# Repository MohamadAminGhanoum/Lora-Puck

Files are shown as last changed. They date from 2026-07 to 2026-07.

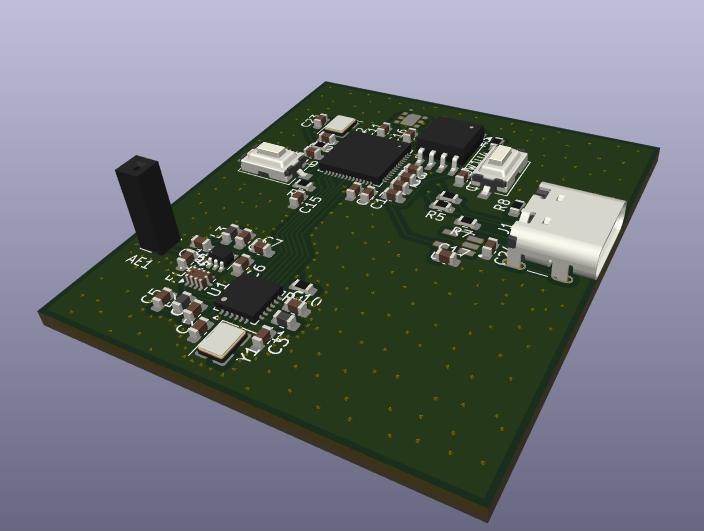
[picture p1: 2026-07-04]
assets/Screenshot 2026-07-03 at 01.11.49.png

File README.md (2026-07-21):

# Lora-Puck
im planning on doing the lorapuck, while adding some simple and accurate sensors, which certainly will make this Lora Puck a lot more useful to me. Im planning to make 2 pcbs, one i keep at home that can track the temperature of e.g my room, and one i can take with me anywhere, and this will allow me to recieve signals from my home LORA, and i will be recieving it to my other LORA puc that i carry with me.
NOTE: as i am making it in the EU, i should follow the european law of max. 868 MHz, and not 915 MHz like USA

## Schematics:



## PCB:



## 3d pic of pcb:




## BOM

|Name |Vendor |Quantity|Price in USD|Link |
|---|---|---|---|---|
|PCB |JLCPCB |5 |10 |JLCPCB |
|100nF capacitor  |LCSC |12 |self-sourced| |
|47nH inductor |LCSC |1 |0.23 |https://www.lcsc.com/product-detail/C440659.html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  |
|HTU21D |LCSC |2 |3.29 |https://www.lcsc.com/product-detail/C83479.html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 |
|RP2040 |LCSC |2 |1.99 |https://www.lcsc.com/product-detail/C2040.html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 |
|SX1262IMLTRT |LCSC |2 |6.51 |https://www.lcsc.com/product-detail/C191341.html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  |
| | | | | |
|AP2112K-3.3TRG1  |LCSC |5 |0.55 |https://www.lcsc.com/product-detail/C23380830.html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|
|W25Q128JVS |LCSC |2 |5.6 |https://www.lcsc.com/product-detail/C97521.html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 |
|10uF capacitor |LCSC |50 |1.75 |https://www.lcsc.com/product-detail/C1691.html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 |
|12nHz crystal |LCSC |20 |0.43 |https://www.lcsc.com/product-detail/C1332832.html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 |
|470nF cap |LCSC |100 |1.15 |https://www.lcsc.com/product-detail/C105526.html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  |
|1k resistor |LCSC |100 |0.76 |https://www.lcsc.com/product-detail/C2907002.html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|
|0900FM15K0039001E|LCSC |1 |0.61 |https://www.lcsc.com/product-detail/C7434807.html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 |
|100 ohm resistor |LCSC |1 |selfsourced | |
|32MHz |LCSC |2 |selfsourced | |
|3.3pF capacitor  |LCSC |100 |1.04 |https://www.lcsc.com/product-detail/C1660.html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 |
| 1uF capacitor |LCSC |50 |1.09 |https://www.lcsc.com/product-detail/C29936.html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  |
|5.1k resistor |LCSC |100 |0.24 |https://www.lcsc.com/product-detail/C2907044.html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|
|USB-c |LCSC |20 |1.41 |https://www.lcsc.com/product-detail/C2765186.html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|
|switch |LCSC |2 |selfsourced | |
|BLM15AX102SN1D |LCSC |100 |1.26 |https://www.lcsc.com/product-detail/C85815.html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  |
|27.4 ohm resistor|LCSC |2 |selfsourced | |
|1nF capacitor |LCSC |1 |1.46 |https://www.lcsc.com/product-detail/C100040.html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 |
| 39pF cap |LCSC |100 |0.52 |https://www.lcsc.com/product-detail/C107049.html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 |
| 15pF cap |LCSC |100 |0.57 |https://www.lcsc.com/product-detail/C107037.html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 |
| 47pF cap |LCSC |100 |0.61 |https://www.lcsc.com/product-detail/C105622.html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 |
| 9.1nH inductor  |LCSC |50 |0.54 |https://www.lcsc.com/product-detail/C395094.html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 |
| 10k resistor |LCSC |100 |0.51 |https://www.lcsc.com/product-detail/C98220.html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  |
|PE4259 |LCSC |2 |1.41 |https://www.lcsc.com/product-detail/C470892.html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 |
|15uH inductor |LCSC |20 |0.73 |https://www.lcsc.com/product-detail/C486329.html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 |
| | | | | |
| |Total cost w. shipping:|50 usd  | | |

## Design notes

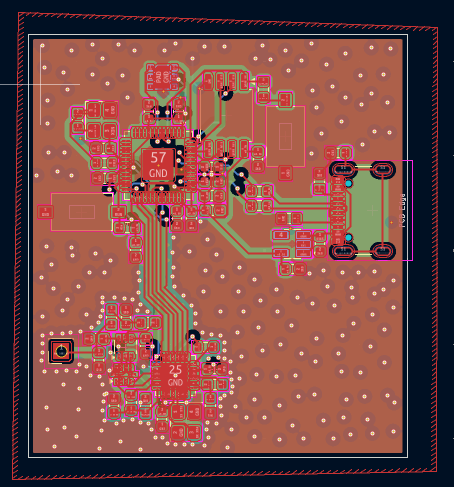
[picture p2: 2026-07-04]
assets/Screenshot 2026-07-03 at 01.11.20.png

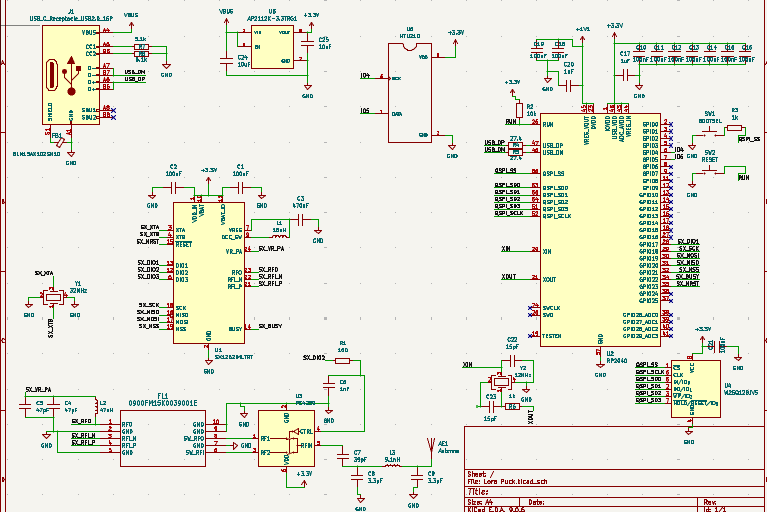
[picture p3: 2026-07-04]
assets/Screenshot 2026-07-04 at 22.49.37.png

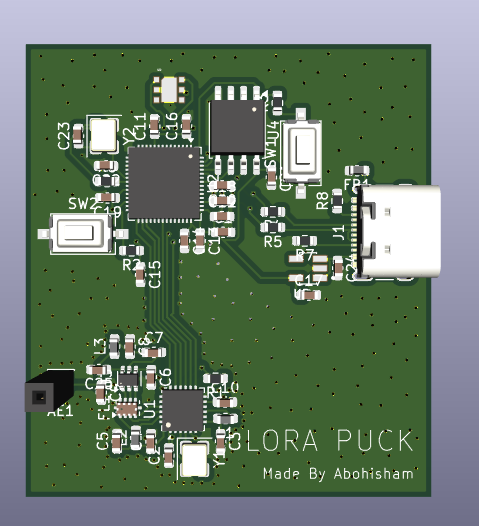
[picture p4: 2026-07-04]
assets/Screenshot 2026-07-03 at 01.14.08.png

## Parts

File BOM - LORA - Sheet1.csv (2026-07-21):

Name | Vendor | Quantity | Price in USD | Link
PCB | JLCPCB | 5 | 10 | JLCPCB
100nF capacitor | LCSC | 12 | self-sourced
47nH inductor | LCSC | 1 | 0.23 | https://www.lcsc.com/product-detail/C440659.html
HTU21D | LCSC | 2 | 3.29 | https://www.lcsc.com/product-detail/C83479.html
RP2040 | LCSC | 2 | 1.99 | https://www.lcsc.com/product-detail/C2040.html
SX1262IMLTRT | LCSC | 2 | 6.51 | https://www.lcsc.com/product-detail/C191341.html
AP2112K-3.3TRG1 | LCSC | 5 | 0.55 | https://www.lcsc.com/product-detail/C23380830.html
W25Q128JVS | LCSC | 2 | 5.6 | https://www.lcsc.com/product-detail/C97521.html
10uF capacitor | LCSC | 50 | 1.75 | https://www.lcsc.com/product-detail/C1691.html
12nHz crystal | LCSC | 20 | 0.43 | https://www.lcsc.com/product-detail/C1332832.html
470nF cap | LCSC | 100 | 1.15 | https://www.lcsc.com/product-detail/C105526.html
1k resistor | LCSC | 100 | 0.76 | https://www.lcsc.com/product-detail/C2907002.html
0900FM15K0039001E | LCSC | 1 | 0.61 | https://www.lcsc.com/product-detail/C7434807.html
100 ohm resistor | LCSC | 1 | selfsourced
32MHz | LCSC | 2 | selfsourced
3.3pF capacitor | LCSC | 100 | 1.04 | https://www.lcsc.com/product-detail/C1660.html
1uF capacitor | LCSC | 50 | 1.09 | https://www.lcsc.com/product-detail/C29936.html
5.1k resistor | LCSC | 100 | 0.24 | https://www.lcsc.com/product-detail/C2907044.html
USB-c | LCSC | 20 | 1.41 | https://www.lcsc.com/product-detail/C2765186.html
switch | LCSC | 2 | selfsourced
BLM15AX102SN1D | LCSC | 100 | 1.26 | https://www.lcsc.com/product-detail/C85815.html
27.4 ohm resistor | LCSC | 2 | selfsourced
1nF capacitor | LCSC | 1 | 1.46 | https://www.lcsc.com/product-detail/C100040.html
39pF cap | LCSC | 100 | 0.52 | https://www.lcsc.com/product-detail/C107049.html
15pF cap | LCSC | 100 | 0.57 | https://www.lcsc.com/product-detail/C107037.html
47pF cap | LCSC | 100 | 0.61 | https://www.lcsc.com/product-detail/C105622.html
9.1nH inductor | LCSC | 50 | 0.54 | https://www.lcsc.com/product-detail/C395094.html
10k resistor | LCSC | 100 | 0.51 | https://www.lcsc.com/product-detail/C98220.html
PE4259 | LCSC | 2 | 1.41 | https://www.lcsc.com/product-detail/C470892.html
15uH inductor | LCSC | 20 | 0.73 | https://www.lcsc.com/product-detail/C486329.html
 | Total cost w. shipping: | 50 usd

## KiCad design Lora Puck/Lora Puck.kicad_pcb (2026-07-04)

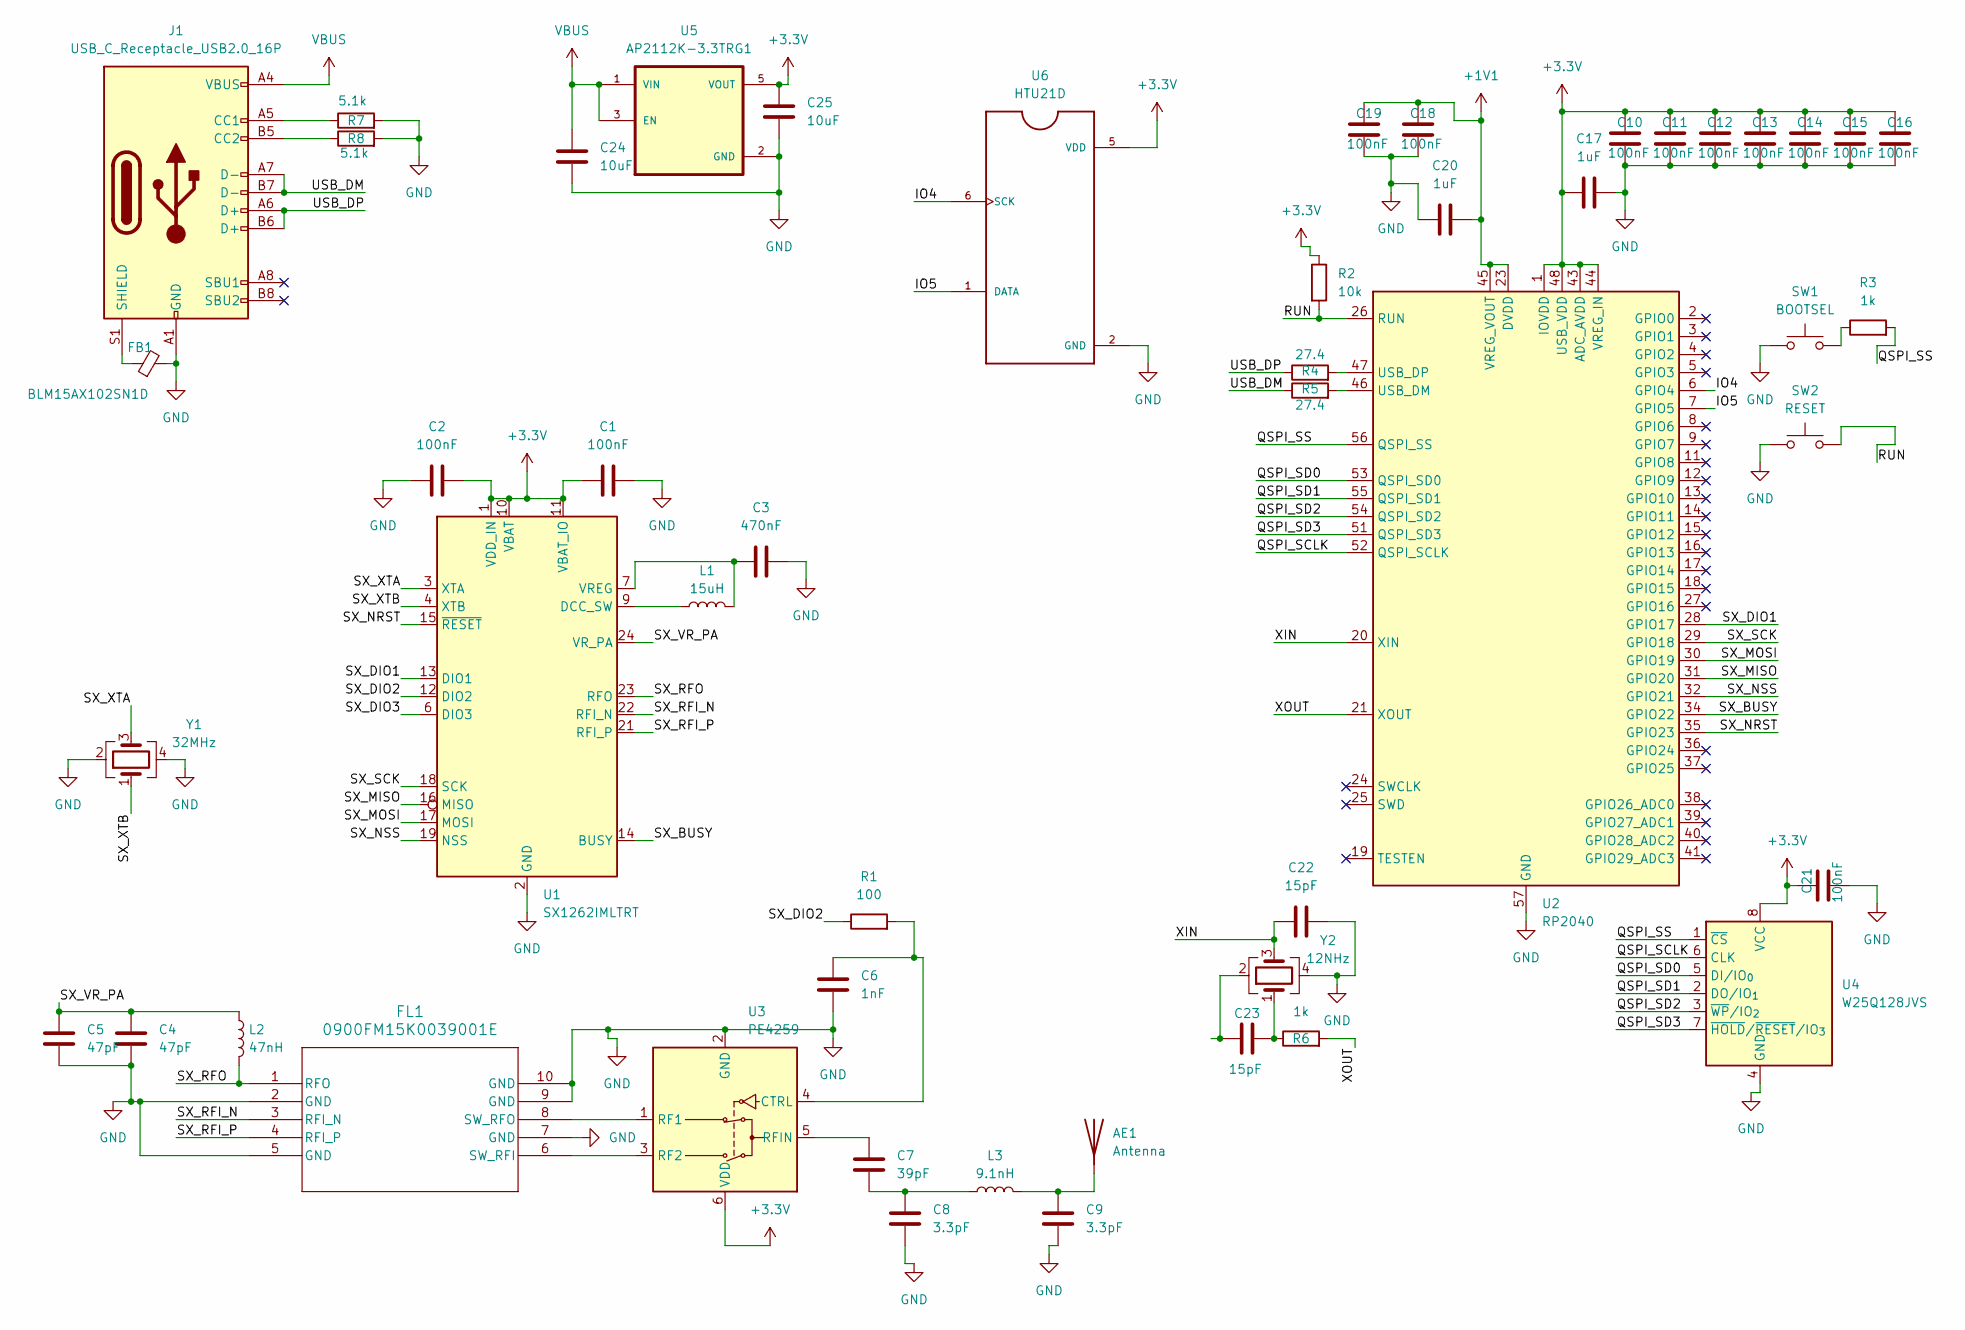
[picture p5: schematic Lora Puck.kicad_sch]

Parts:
AE1: Antenna; PinSocket_1x01_P2.54mm_Vertical
C1, C2, C10, C11, C12, C13, C14, C15, C16, C18, C19, C21: 100nF; C_0603_1608Metric
C3: 470nF; C_0603_1608Metric
C4, C5: 47pF; C_0603_1608Metric
C6: 1nF; C_0603_1608Metric
C7: 39pF; C_0603_1608Metric
C8, C9: 3.3pF; C_0603_1608Metric
C17, C20: 1uF; C_0603_1608Metric
C22, C23: 15pF; C_0603_1608Metric
C24, C25: 10uF; C_0603_1608Metric
FB1: BLM15AX102SN1D; L_0603_1608Metric
FL1: 0900FM15K0039001E; Balun_Johanson_0900FM15K0039
J1: USB_C_Receptacle_USB2.0_16P; USB_C_Receptacle_GCT_USB4105-xx-A_16P_TopMnt_Horizontal
L1: 15uH; L_0603_1608Metric
L2: 47nH; L_0603_1608Metric
L3: 9.1nH; L_0603_1608Metric
R1: 100; R_0603_1608Metric
R2: 10k; R_0603_1608Metric
R3, R6: 1k; R_0603_1608Metric
R4, R5: 27.4; R_0603_1608Metric
R7, R8: 5.1k; R_0603_1608Metric
SW1: BOOTSEL; SW_Tactile_SPST_NO_Straight_CK_PTS636Sx25SMTRLFS
SW2: RESET; SW_Tactile_SPST_NO_Straight_CK_PTS636Sx25SMTRLFS
U1: SX1262IMLTRT; QFN-24-1EP_4x4mm_P0.5mm_EP2.6x2.6mm
U2: RP2040; QFN-56-1EP_7x7mm_P0.4mm_EP3.2x3.2mm
U3: PE4259; SOT-363_SC-70-6
U4: W25Q128JVS; SOIC-8_5.3x5.3mm_P1.27mm
U5: AP2112K-3.3TRG1; SOT95P285X140-5N; PARTREV 2-2
U6: HTU21D; QFN100P300X300X100-7N
Y1: 32MHz; Crystal_SMD_3225-4Pin_3.2x2.5mm
Y2: 12NHz; Crystal_SMD_Abracon_ABM8G-4Pin_3.2x2.5mm

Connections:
+1V1: C18.1, C19.1, C20.2, U2.23 (DVDD), U2.45 (VREG_VOUT), U2.50 (DVDD)
+3.3V: C1.1, C2.2, C10.1, C11.1, C12.1, C13.1, C14.1, C15.1, C16.1, C17.1, C21.1, C25.1, R2.1, U1.1 (VDD_IN), U1.10 (VBAT), U1.11 (VBAT_IO), U2.1 (IOVDD), U2.10 (IOVDD), U2.22 (IOVDD), U2.33 (IOVDD), U2.42 (IOVDD), U2.43 (ADC_AVDD), U2.44 (VREG_IN), U2.48 (USB_VDD), U2.49 (IOVDD), U3.6 (VDD), U4.8 (VCC), U5.5 (VOUT), U6.5 (VDD)
/IO4: U2.6 (GPIO4), U6.6 (SCK)
/IO5: U2.7 (GPIO5), U6.1 (DATA)
/QSPI_SCLK: U2.52 (QSPI_SCLK), U4.6 (CLK)
/QSPI_SD0: U2.53 (QSPI_SD0), U4.5 (DI/IO_{0})
/QSPI_SD1: U2.55 (QSPI_SD1), U4.2 (DO/IO_{1})
/QSPI_SD2: U2.54 (QSPI_SD2), U4.3 (~WP/IO_{2})
/QSPI_SD3: U2.51 (QSPI_SD3), U4.7 (~HOLD/~RESET/IO_{3})
/QSPI_SS: R3.2, U2.56 (QSPI_SS), U4.1 (~CS)
/RUN: R2.2, SW2.2, U2.26 (RUN)
/SX_BUSY: U1.14 (BUSY), U2.34 (GPIO22)
/SX_DIO1: U1.13 (DIO1), U2.28 (GPIO17)
/SX_DIO2: R1.1, U1.12 (DIO2)
/SX_DIO3: U1.6 (DIO3)
/SX_MISO: U1.16 (MISO), U2.31 (GPIO20)
/SX_MOSI: U1.17 (MOSI), U2.30 (GPIO19)
/SX_NRST: U1.15 (~RESET), U2.35 (GPIO23)
/SX_NSS: U1.19 (NSS), U2.32 (GPIO21)
/SX_RFI_N: FL1.3 (RFI_N), U1.22 (RFI_N)
/SX_RFI_P: FL1.4 (RFI_P), U1.21 (RFI_P)
/SX_RFO: FL1.1 (RFO), L2.2, U1.23 (RFO)
/SX_SCK: U1.18 (SCK), U2.29 (GPIO18)
/SX_VR_PA: C4.1, C5.1, L2.1, U1.24 (VR_PA)
/SX_XTA: U1.3 (XTA), Y1.3
/SX_XTB: U1.4 (XTB), Y1.1
/USB_DM: J1.A7 (D-), J1.B7 (D-), R5.1
/USB_DP: J1.A6 (D+), J1.B6 (D+), R4.1
/XIN: C22.1, U2.20 (XIN), Y2.3
/XOUT: R6.2, U2.21 (XOUT)
GND: C1.2, C2.1, C3.2, C4.2, C5.2, C6.2, C8.1, C9.2, C10.2, C11.2, C12.2, C13.2, C14.2, C15.2, C16.2, C17.2, C18.2, C19.2, C20.1, C21.2, C22.2, C24.2, C25.2, FB1.2, FL1.2 (GND), FL1.5 (GND), FL1.7 (GND), FL1.9 (GND), FL1.10 (GND), J1.A1 (GND), J1.A12 (GND), J1.B1 (GND), J1.B12 (GND), R7.2, R8.2, SW1.1, SW2.1, U1.2 (GND), U1.5 (GND), U1.8 (GND), U1.20 (GND), U1.25 (GND), U2.57 (GND), U3.2 (GND), U4.4 (GND), U5.2 (GND), U6.2 (GND), U6.PAD (GND), Y1.2, Y1.4, Y2.4
unnamed: AE1.1 (A), C9.1, L3.2
unnamed: C7.1, C8.2, L3.1
unnamed: C23.1, Y2.2
unnamed: C23.2, R6.1, Y2.1
unnamed: FL1.6 (SW_RFI), U3.3 (RF2)
unnamed: FL1.8 (SW_RFO), U3.1 (RF1)
unnamed: J1.A5 (CC1), R7.1
unnamed: J1.B5 (CC2), R8.1
unnamed: FB1.1, J1.S1 (SHIELD)
unnamed: R3.1, SW1.2
unnamed: L1.1, U1.9 (DCC_SW)
unnamed: C3.1, L1.2, U1.7 (VREG)
unnamed: R5.2, U2.46 (USB_DM)
unnamed: R4.2, U2.47 (USB_DP)
unnamed: C6.1, R1.2, U3.4 (CTRL)
unnamed: C7.2, U3.5 (RFIN)
VBUS: C24.1, J1.A4 (VBUS), J1.A9 (VBUS), J1.B4 (VBUS), J1.B9 (VBUS), U5.1 (VIN), U5.3 (EN)

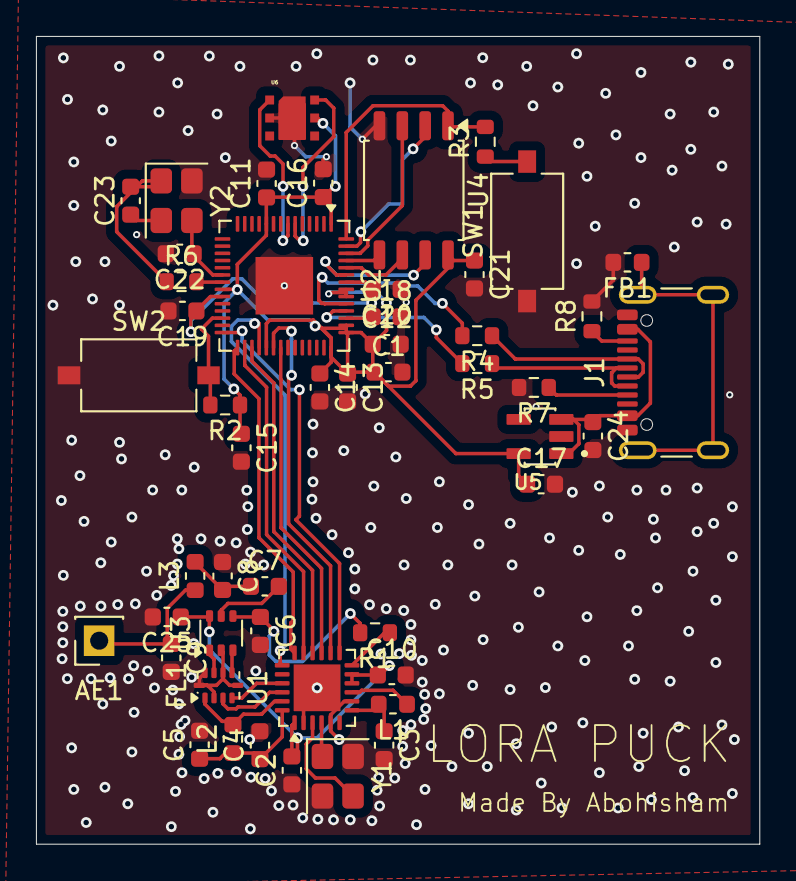
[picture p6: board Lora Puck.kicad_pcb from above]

Board: 4 copper layers, 40.2 x 44.9 mm, 50 parts (0 on the bottom side), 47 nets.

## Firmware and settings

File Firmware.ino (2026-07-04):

#include <RadioLib.h>

// Define the SPI and control pins matching the LoRa Puck hardware layout
// Double-check your schematic's RP2040-to-SX1262 pin connections!
#define LORA_NSS    8   // Chip Select (NSS)
#define LORA_DIO1   9   // Busy/Interrupt line (DIO1)
#define LORA_NRST   13  // Reset pin (NRST)
#define LORA_BUSY   14  // Busy indicator pin (BUSY)

// Initialize the SX1262 module instance
SX1262 radio = new Module(LORA_NSS, LORA_DIO1, LORA_NRST, LORA_BUSY);

void setup() {
  Serial.begin(115200);
  while (!Serial); // Wait for serial monitor to open
  
  Serial.println(F("[SX1262] Initializing transceiver configuration..."));

  // Initialize SX1262 with European 868MHz settings
  // Carrier Frequency: 868.1 MHz
  // Bandwidth: 125.0 kHz (Standard LoRa)
  // Spreading Factor: 9 (Good balance of range and speed)
  // Coding Rate: 7 (CR 4/7 for error correction robustness)
  // Sync Word: 0x12 (Private network sync word)
  // Output Power: 10 dBm (10 mW - well below Denmark's 25 mW legal ceiling)
  // Preamble Length: 8 symbols
  int state = radio.begin(868.1, 125.0, 9, 7, 0x12, 10, 8);

  if (state == RADIOLIB_ERR_NONE) {
    Serial.println(F("[SX1262] Initialization successful! Board is legal & optimized for EU."));
  } else {
    Serial.print(F("[SX1262] Initialization failed, code: "));
    Serial.println(state);
    while (true); // Halt execution if hardware matching fails
  }
}

int packetCounter = 0;

void loop() {
  Serial.print(F("[SX1262] Transmitting test packet #"));
  Serial.println(packetCounter);

  // Construct a simple telemetry text string
  String str = "Puck Ping #" + String(packetCounter);
  
  // Transmit the packet (this blocks until transmission finishes)
  int state = radio.transmit(str);

  if (state == RADIOLIB_ERR_NONE) {
    Serial.println(F("[SX1262] Packet sent successfully!"));
    
    // Print the measured data rate performance
    Serial.print(F("[SX1262] Data rate:\t"));
    Serial.print(radio.getDataRate());
    Serial.println(F(" bps"));
  } else if (state == RADIOLIB_ERR_TX_TIMEOUT) {
    Serial.println(F("[SX1262] Error: Transmission timed out!"));
  } else {
    Serial.print(F("[SX1262] Transmission failed, code: "));
    Serial.println(state);
  }

  packetCounter++;

  Serial.println(F("[System] Cooling down radio to respect duty-cycle regulations..."));
  delay(30000); 
}
